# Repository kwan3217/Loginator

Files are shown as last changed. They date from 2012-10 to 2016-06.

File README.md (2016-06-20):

# Loginator
The [https://www.sparkfun.com/products/retired/8627 Sparkfun Logomatic] is a single-board computer marketed as a data logger. When I got mine, it didn't take me long to realize that this was a much more powerful computer, capable of such things as robot control. I took the original hardware design and made several derivative boards, including one which has been in space, one which has logged data on rollercoasters around the country, and one which has been to Europe and back.

This code is a complete rewrite of the firmware in C++. All original Sparkfun code has been replaced. Having said that, in the spirit of Open Source, the software is GPL 3.0 because I choose it to be, and the hardware design is CC-BY-SA because it is still derived from the original Sparkfun design.

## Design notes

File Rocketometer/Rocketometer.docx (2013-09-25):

Rocketometer Operator’s guide

Chris Jeppesen, 24 Sep 2013

1) Mechanical

The user interface includes two buttons and one power switch. The buttons include one reset button, and one button intended to switch from USB Mass Storage readout to main Rocketometer mode (boot). The reset button has been disabled by removing the solder bridge next to it. The boot button doesn’t actually do anything, so it doesn’t need to be rendered inert.

The power switch should be glued or otherwise secured in the ON position, with the switch closer to the word ON and closer to the edge of the board.

The SD card should also be glued into place, with something that can be peeled off to remove the card after flight.

Some components on the board are very close to the mounting holes. They are technically out of the keepout zone for the screw head, but too close for comfort. It would be great if rubber, paper, or some other non-conducting washers could be used to protect these components.

2) Indicator lights

The board has four colors of lights, yellow, red, green, blue.

The yellow light is on whenever the charging circuit is charging the battery. It is off when there is no external power OR when the battery is fully charged.

The RGB diode is green for the first few seconds during board startup. It then flickers through all of the colors slowly when the board is not vertical and has not been for 20 minutes. It flickers quickly when the board has been vertical within the last 20 minutes. To be precise, each time it writes a sector to the SD card, it toggles one of the colors on or off, and it cycles through the colors in turn. Since more data is generated in vertical mode, sectors are written more quickly, so the light blinks more quickly.

When the board is in slow recording mode, it flickers one light on, all off, next light on, etc, with the light on for noticeably less than 1 second. When the board is in blinklock (see Trouble below), the light is on for exactly 1 second, then off for 1 second, etc. This is noticeably slower than slow recording mode. It takes a bit of care to notice the difference, but no special tools other than the Mark I Eyeball.

3) Power

The board has a +5V input, which it uses to run all functions and charge the battery while powered. When unpowered, the board automatically and seamlessly switches to battery power. This board, with slightly different software, has been observed to run for about 2.5 hours before draining the battery. This means that the board has a power draw of significantly less than 100mA. The battery is rated at 110mAh.

The +5V input also charges the battery. The board carries the proper LiPo charging circuit and the battery has an integrated LiPo protection circuit which among other things prevents overcharge and overdischarge. Charging current is limited to 100mA, which has been observed to fully charge the battery in about 1.5 hours.

4) Trouble

If the board detects an unrecoverable error, it will enter a mode called blinklock. In this mode, the RGB diode blinks slowly, 1 second on, 1 second off. The blink is a simple binary code. The error number is communicated by blinking green for a 1 bit and red for a 0 bit, least significant bit first. When all 1 bits have been blinked, the blue light blinks indicating that the full number has been blinked out, then the process repeats, blinking the same number forever until the device is reset or power-cycled.

Let’s say the blink code is 404. In binary this is 1_1001_0100, so the code would be R R G R G R R G G B endlessly repeated. The first blink after a blue light is the first blink in this cycle.

There is no table of blink codes except for the source code. The code would have to be examined to determine the exact cause. If you encounter a blink code, notify me and disable power (and battery if possible, otherwise you have to wait for the battery to drain) to reset the board.

5) File generation

The Rocketometer writes files in the standard FAT32 filesystem, with some tweaks. In particular, the card has been formatted with the largest possible cluster size and only one file allocation table, to optimize writing speed. Any normal operating system should be able to read this card with no issue, and it has been tested with standard Microsoft Windows 7 and Linux, which did read it with no issue.

Files are named in the format RKTO%04d.SDS, where %04d indicates four decimal digits. These digits are the serial number for the file.

Each time the board starts up, it will search the card, starting with a serial number of 0 and incrementing it by 10 each time. When it does not find a file corresponding to this serial number, it stops searching and creates a new file with this number. In this case, if the card is repeatedly restarted, it will count

RKTO0000.SDS

RKTO0010.SDS

RKTO0020.SDS

etc.

Files are capped at 1GiB. When the current file size reaches this amount, the file is closed. The card is searched again starting at the next higher serial number and incrementing by 1 each time.

At high data rate, the card will hit this 1GiB file size in about 1 day. If the card ran for 10 days straight starting with a serial number of 0, it would reach serial number 10. This still isn’t a problem, when the card is reset it will skip that 10 and go on to the next multiple. No data will be overwritten.

The root directory can hold 2048 files. It is unlikely that this number will be reached, as it would involve being power-cycled that many times.

Since this is a 16GiB card, it can record for about 16 days at high rate and 160 days at low rate. There should be no problem with either number of files or data volume.

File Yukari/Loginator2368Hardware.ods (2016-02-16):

Hardware type | Serial Number
3 | 1 | Loginator2368 Hardware | Loginator2368 Hardware

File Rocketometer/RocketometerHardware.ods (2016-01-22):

Hardware type | Serial Number
2 | 2 | Rocketometer Hardware | Rocketometer Hardware

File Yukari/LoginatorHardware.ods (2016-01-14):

Hardware type | Serial Number
1 | 1 | Loginator Hardware | Loginator Hardware

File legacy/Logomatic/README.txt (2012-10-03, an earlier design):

Logomatic Firmware with SDHC and FAT32
Chris Jeppesen
http://stkwans.blogspot.com/
19 May 2012

OK, this empty file came with the package, so I am going to use it. This is the
stock Logomatic firmware with the bare minimum adjustments needed to use the
latest sd_raw and fat libraries which have SDHC and fat32 activated, 
respectively. To use, copy FW.SFE to the root directory of the Logomatic card,
then power up the card with the USB disconnected. The USB bootloader will
copy the firmware to the controller's flash memory then delete FW.SFE off of 
the card. Once done, the logger program should work exactly as before, just 
with the ability to work with SDHC cards and FAT32 file systems. The program 
still works with SD normal capacity and FAT16 file systems as well.

While this program recognizes SDHC and FAT32, by itself it does not make the 
bootloader do also. I have a USB bootloader modified similarly, but if you 
don't use that bootloader, you will need to write FW.SFE to ad SD normal 
capacity (<=2GB, not marked SDHC) card formatted as FAT16. It still might not 
work, since the bootloader tries to read the card each time it starts up to see 
if it needs to install FW.SFE, and since it can't read an SDHC card, it may 
never boot the main firmware. Best to get my USB bootloader also, just in case. 
Find it on my blog in the same place you found this code.

Sparkfun published the code with no explicit license, but since so much of it 
is GPL and LGPL, I can presume that all of it is, so my changes are GPL'd also. 
I really didn't do that much. I stand on the shoulders of giants. Anyone is 
allowed to do whatever they want with it within the limits of the GPL (3.0 or 
later). Specifically, Sparkfun is allowed to use my changes and do whatever 
they need to do to put this program onto production Logomatics, just as they 
have been doing, whether this is technically allowed by the GPL or not.

The code works for me, but there are almost certainly bugs in it. It is hoped 
that this code is useful, but there is NO WARRANTY, as specified by the GPL. If 
this code causes your house to burn down, it's your fault. If you have any bug 
fixes, you are welcome to send them to me, and if the changes work for me, I 
will include them in the hypothetical next revision.

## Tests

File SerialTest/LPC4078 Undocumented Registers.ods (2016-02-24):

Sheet: Sheet1
0 | 1048576 | 100000 |  |  | base | 1048576
1 | 1048580 | 100004
2 | 1048584 | 100008
3 | 1048588 | 10000C
4 | 1048592 | 100010
5 | 1048596 | 100014
6 | 1048600 | 100018
7 | 1048604 | 10001C
8 | 1048608 | 100020
9 | 1048612 | 100024
10 | 1048616 | 100028
11 | 1048620 | 10002C
12 | 1048624 | 100030
13 | 1048628 | 100034
14 | 1048632 | 100038
15 | 1048636 | 10003C
16 | 1048640 | 100040
17 | 1048644 | 100044
18 | 1048648 | 100048
19 | 1048652 | 10004C
20 | 1048656 | 100050
21 | 1048660 | 100054
22 | 1048664 | 100058
23 | 1048668 | 10005C
24 | 1048672 | 100060
25 | 1048676 | 100064
26 | 1048680 | 100068
27 | 1048684 | 10006C
28 | 1048688 | 100070
29 | 1048692 | 100074
30 | 1048696 | 100078
31 | 1048700 | 10007C
32 | 1048704 | 100080
33 | 1048708 | 100084
34 | 1048712 | 100088
35 | 1048716 | 10008C
36 | 1048720 | 100090
37 | 1048724 | 100094
38 | 1048728 | 100098
39 | 1048732 | 10009C
40 | 1048736 | 1000A0
41 | 1048740 | 1000A4
42 | 1048744 | 1000A8
43 | 1048748 | 1000AC
44 | 1048752 | 1000B0
45 | 1048756 | 1000B4
46 | 1048760 | 1000B8
47 | 1048764 | 1000BC
48 | 1048768 | 1000C0
49 | 1048772 | 1000C4
50 | 1048776 | 1000C8
51 | 1048780 | 1000CC
52 | 1048784 | 1000D0
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

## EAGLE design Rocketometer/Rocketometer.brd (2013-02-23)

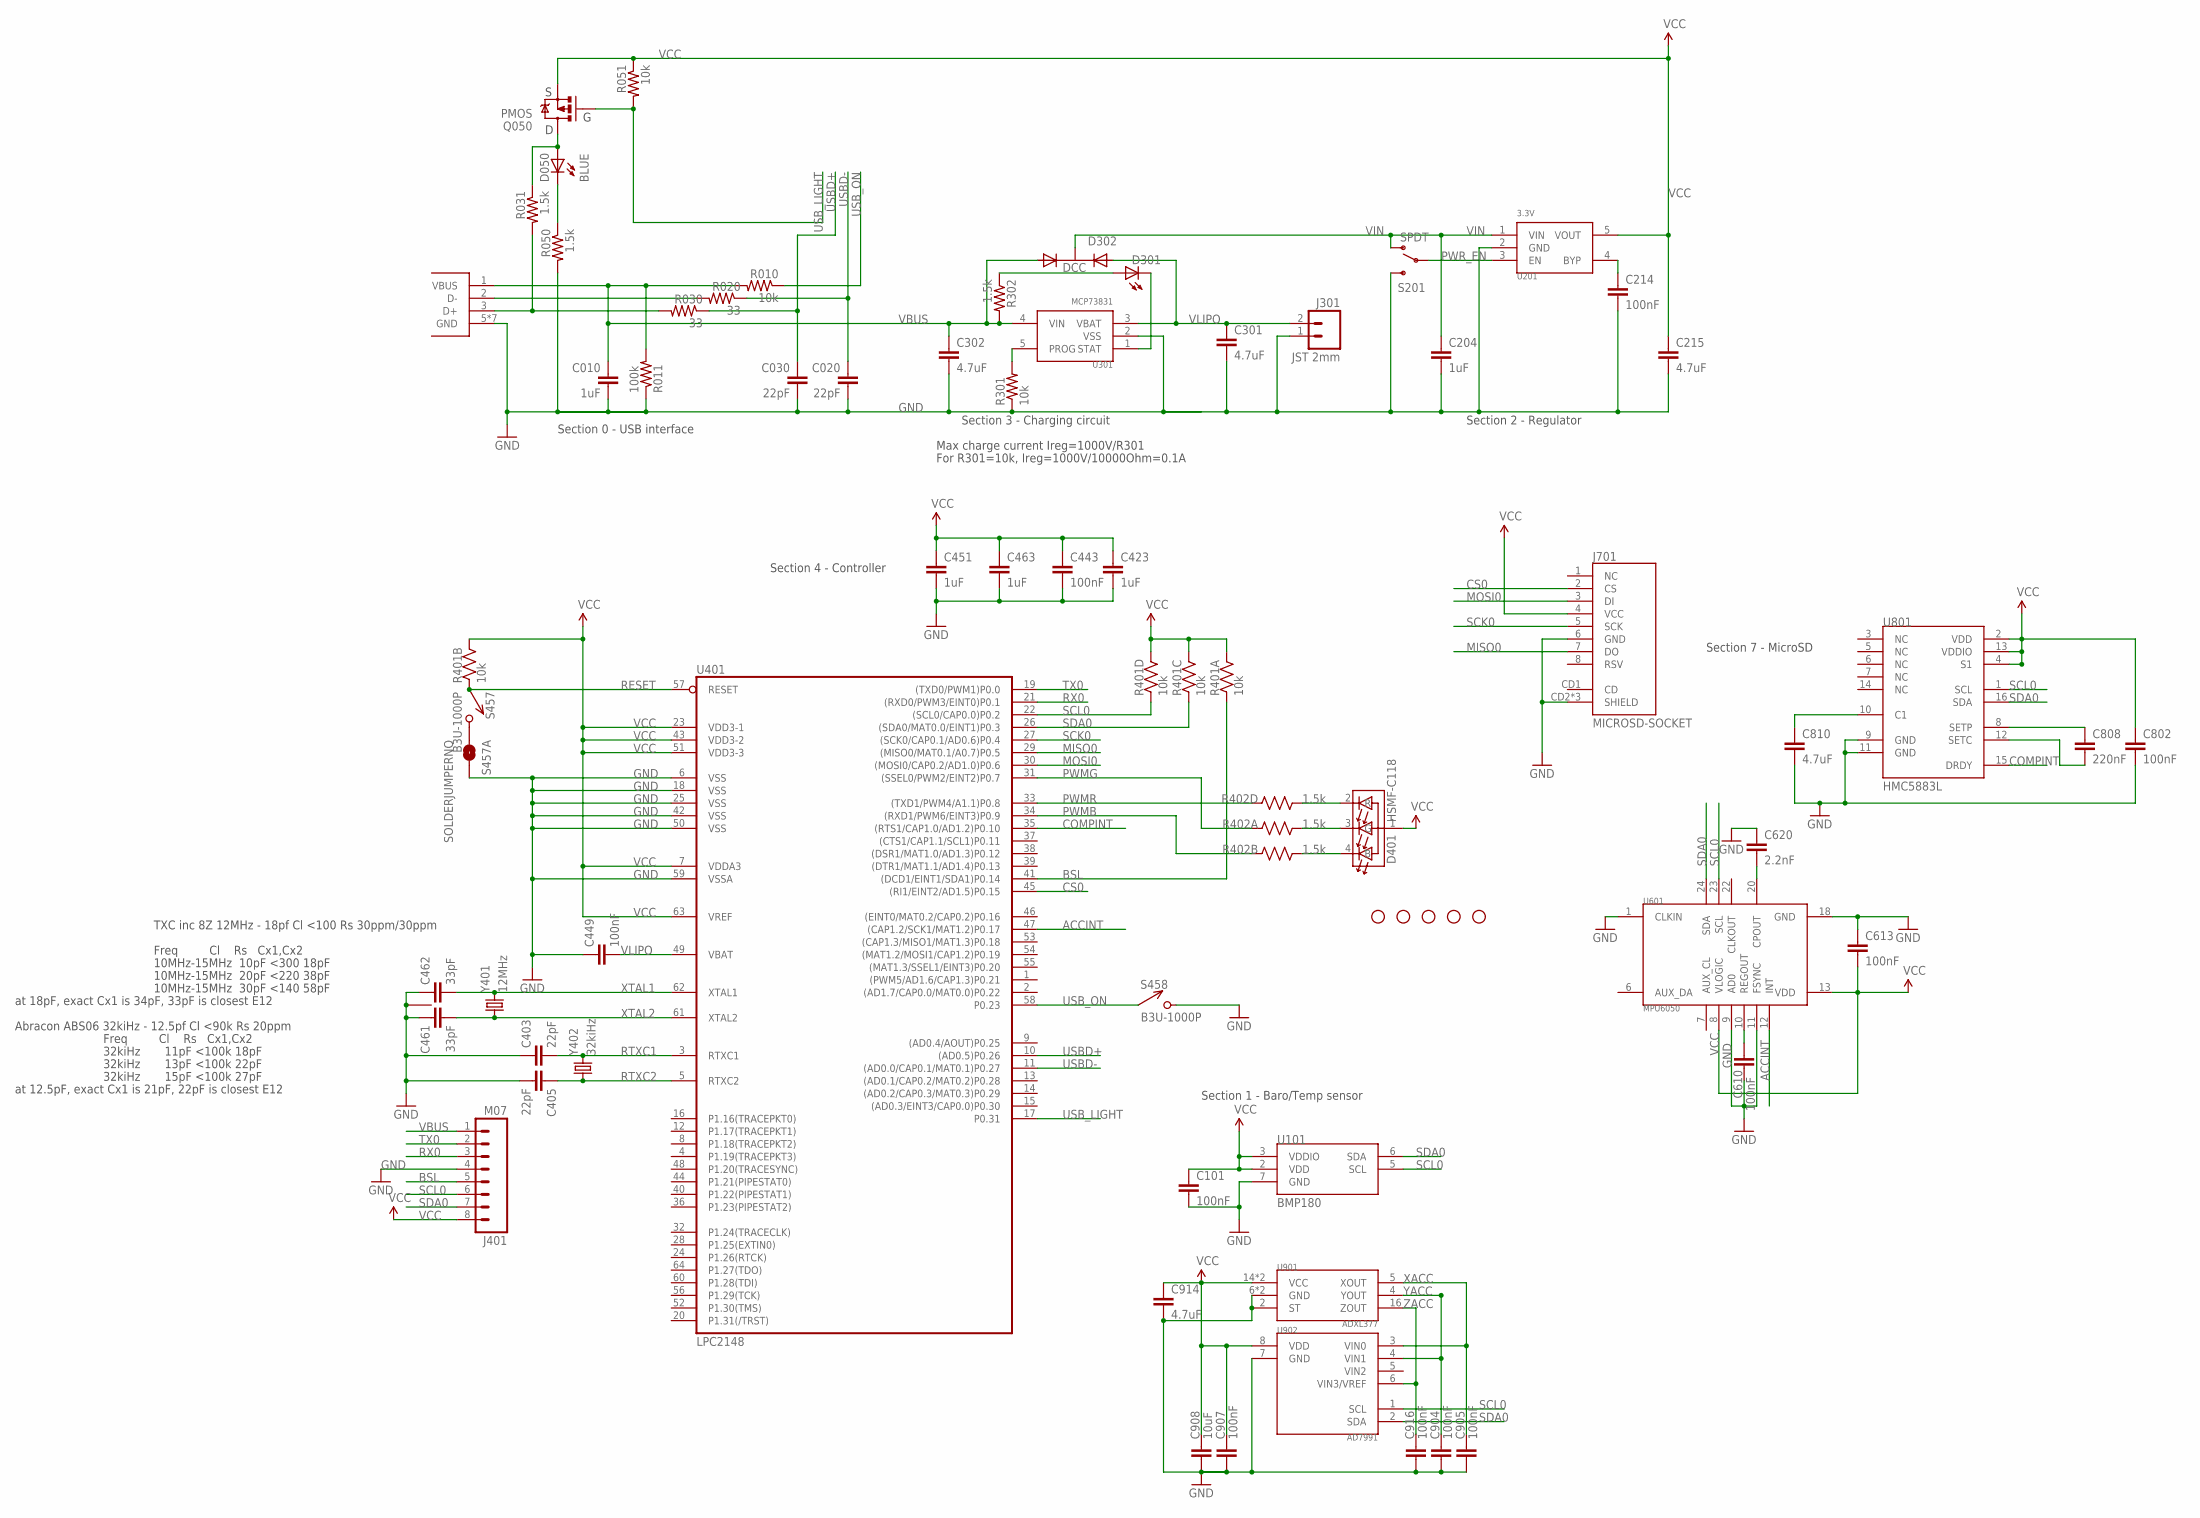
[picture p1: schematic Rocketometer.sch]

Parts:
C010, C204, C423, C451, C463: 1uF; 0402-CAP; DIGIKEY 445-4114-1-ND
C020, C030, C403, C405: 22pF; 0402-CAP; DIGIKEY 445-1239-1-ND
C101, C214, C443, C449, C610, C613, C802, C904, C905, C907, C916: 100nF; 0402-CAP; DIGIKEY 445-1265-1-ND
C215, C301, C302, C810, C914: 4.7uF; 0402-CAP; DIGIKEY 445-7395-1-ND
C461, C462: 33pF; 0402-CAP; DIGIKEY 445-1241-1-ND
C620: 2.2nF; 0402-CAP; DIGIKEY 445-1257-1-ND
C808: 220nF; 0402-CAP; DIGIKEY 445-5938-1-ND
C908: 10uF; 0603-CAP; DIGIKEY 445-7486-1-ND
D050: BLUE; LED-0603; DIGIKEY 350-2037-1-ND
D301: YELLOW; LED-0603; DIGIKEY 350-2032-1-ND
D302: DCC; SOT-23-3; DIGIKEY 568-6500-1-ND
D401: HSMF-C118; DIGIKEY 516-1778-1-ND
J001: USB_MICROB_JST; UB-MC5BR3-SD204-4S; DIGIKEY 455-2562-1-ND
J301: JST 2mm; JST-2-SMD; DIGIKEY 455-1749-1-ND
J401: M07; 1X08; DIGIKEY $NOPART
J701: MICROSD-SOCKET; MICROSD-SOCKET-PP; DIGIKEY 101-00581-59-1-ND
JP1, JP2, JP3, JP4, JP5: STAND-OFFTIGHT; STAND-OFF-TIGHT; DIGIKEY $NOPART
Q050: PMOS; SOT23-3; DIGIKEY NTR1P02T1GOSCT-ND
R010, R051, R301: 10k; 0402-RES; DIGIKEY P10.0KLCT-ND
R011: 100k; 0402-RES; DIGIKEY P100KLCT-ND
R020, R030: 33; 0402-RES; DIGIKEY P33.0LCT-ND
R031, R050, R302: 1.5k; 0402-RES; DIGIKEY P1.50KLCT-ND
R401: 10k; CRA04; DIGIKEY CRA4S810KCT-ND
R402: 1.5k; CRA04; DIGIKEY CRA4S81.5KCT-ND
S201: SPDT; AYZ0202; DIGIKEY 401-2013-1-ND
S457, S458: B3U-1000P; DIGIKEY SW1020CT-ND
S457A: SOLDERJUMPERNO; SJ_2S-NO; DIGIKEY $NOPART
U101: BMP180; DIGIKEY 828-1027-1-ND
U201: 3.3V; SOT-23-5; DIGIKEY 576-1910-1-ND
U301: MCP73831; SOT-23-5; DIGIKEY 576-1910-1-ND
U401: LPC2148; SQFP-S-10X10-64; DIGIKEY 568-1765-ND
U601: MPU6050; MPU60X0; DIGIKEY $NOPART
U801: HMC5883L; 16LPCC; DIGIKEY 342-1082-1-ND
U901: ADXL377; DIGIKEY ADXL377BCPZ-RL7CT-ND
U902: AD7991; SOT-23-8; DIGIKEY AD7991YRJZ-0500RL7CT-ND
Y401: 12MHz; CRYSTAL_SMD_2MM_2_5MM; DIGIKEY 887-1487-1-ND
Y402: 32kiHz; ABS06; DIGIKEY 535-10104-1-ND

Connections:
ACCINT: U401.47 ((CAP1.2/SCK1/MAT1.2)P0.17), U601.12 (INT)
BSL: J401.5, R401.1, U401.41 ((DCD1/EINT1/SDA1)P0.14)
COMPINT: U401.35 ((RTS1/CAP1.0/AD1.2)P0.10), U801.15 (DRDY)
CONN_D+: J001.3 (D+), R030.2, R031.2
CONN_D-: J001.2 (D-), R020.2
CS0: J701.2 (CS), U401.45 ((RI1/EINT2/AD1.5)P0.15)
GND: C010.2, C020.2, C030.2, C101.2, C204.2, C214.2, C215.2, C301.2, C302.2, C403.1, C405.2, C423.2, C443.2, C449.1, C451.2, C461.1, C462.1, C463.2, C610.2, C613.1, C620.1, C802.2, C810.2, C904.2, C905.2, C907.2, C908.2, C914.2, C916.2, J001.5 (GND), J001.P$6 (GND), J001.P$7 (GND), J001.P$8 (GND), J001.P$9 (GND), J001.P$10 (GND), J001.P$11 (GND), J301.1, J401.4, J701.6 (GND), J701.CD2 (SHIELD), J701.GND1 (SHIELD), J701.GND3 (SHIELD), R011.1, R050.2, R301.1, S201.3 (S), S457A.2, S458.P$2 (2), U101.7 (GND), U201.2 (GND), U301.2 (VSS), U401.6 (VSS), U401.18 (VSS), U401.25 (VSS), U401.42 (VSS), U401.50 (VSS), U401.59 (VSSA), U601.1 (CLKIN), U601.9 (AD0), U601.11 (FSYNC), U601.18 (GND), U801.9 (GND), U801.11 (GND), U901.2 (ST), U901.6 (GND), U901.7 (GND), U902.7 (GND), Y401.2 (1), Y401.4 (1)
MISO0: J701.7 (DO), U401.29 ((MISO0/MAT0.1/A0.7)P0.5)
MOSI0: J701.3 (DI), U401.30 ((MOSI0/CAP0.2/AD1.0)P0.6)
unnamed: C620.2, U601.20 (CPOUT)
unnamed: R301.2, U301.5 (PROG)
unnamed: D301.C, U301.1 (STAT)
unnamed: D301.A, R302.1
unnamed: D050.A, Q050.3 (D), R031.1
unnamed: D050.C, R050.1
unnamed: S457.P$2 (2), S457A.1
unnamed: C610.1, U601.10 (REGOUT)
unnamed: C808.1, U801.8 (SETP)
unnamed: C808.2, U801.12 (SETC)
unnamed: C810.1, U801.10 (C1)
unnamed: C214.1, U201.4 (BYP)
PWMB: R402.7 (2), U401.34 ((RXD1/PWM6/EINT3)P0.9)
PWMG: R402.8 (2), U401.31 ((SSEL0/PWM2/EINT2)P0.7)
PWMR: R402.5 (2), U401.33 ((TXD1/PWM4/A1.1)P0.8)
PWR_EN: S201.2, U201.3 (EN)
QWMB: D401.4 (B), R402.2 (1)
QWMG: D401.3 (G), R402.1
QWMR: D401.2 (R), R402.4 (1)
RESET: R401.2 (1), S457.P$1 (1), U401.57 (RESET)
RTXC1: C403.2, U401.3 (RTXC1), Y402.2
RTXC2: C405.1, U401.5 (RTXC2), Y402.1
RX0: J401.3, U401.21 ((RXD0/PWM3/EINT0)P0.1)
SCK0: J701.5 (SCK), U401.27 ((SCK0/CAP0.1/AD0.6)P0.4)
SCL0: J401.6, R401.4 (1), U101.5 (SCL), U401.22 ((SCL0/CAP0.0)P0.2), U601.23 (SCL), U801.1 (SCL), U902.1 (SCL)
SDA0: J401.7, R401.3 (1), U101.6 (SDA), U401.26 ((SDA0/MAT0.0/EINT1)P0.3), U601.24 (SDA), U801.16 (SDA), U902.2 (SDA)
TX0: J401.2, U401.19 ((TXD0/PWM1)P0.0)
USBD+: C030.1, R030.1, U401.10 ((AD0.5)P0.26)
USBD-: C020.1, R020.1, U401.11 ((AD0.0/CAP0.1/MAT0.1)P0.27)
USB_LIGHT: Q050.1 (G), R051.2, U401.17 (P0.31)
USB_ON: R010.1, S458.P$1 (1), U401.58 (P0.23)
VBUS: C010.1, C302.1, D302.1 (A1), J001.1 (VBUS), J401.1, R010.2, R011.2, R302.2, U301.4 (VIN)
VCC: C101.1, C215.1, C423.1, C443.1, C451.1, C463.1, C613.2, C802.1, C907.1, C908.1, C914.1, D401.1 (A), J401.8, J701.4 (VCC), Q050.2 (S), R051.1, R401.5 (2), R401.6 (2), R401.7 (2), R401.8 (2), U101.2 (VDD), U101.3 (VDDIO), U201.5 (VOUT), U401.7 (VDDA3), U401.23 (VDD3-1), U401.43 (VDD3-2), U401.51 (VDD3-3), U401.63 (VREF), U601.8 (VLOGIC), U601.13 (VDD), U801.2 (VDD), U801.4 (S1), U801.13 (VDDIO), U901.14 (VCC), U901.15 (VCC), U902.8 (VDD)
VIN: C204.1, D302.3 (K), S201.1 (O), U201.1 (VIN)
VLIPO: C301.1, C449.2, D302.2 (A2), J301.2, U301.3 (VBAT), U401.49 (VBAT)
XACC: C905.1, U901.5 (XOUT), U902.3 (VIN0)
XTAL1: C462.2, U401.62 (XTAL1), Y401.3 (2)
XTAL2: C461.2, U401.61 (XTAL2), Y401.1
YACC: C904.1, U901.4 (YOUT), U902.4 (VIN1)
ZACC: C916.1, U901.16 (ZOUT), U902.6 (VIN3/VREF)

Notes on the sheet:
Section 2 - Regulator
Section 3 - Charging circuit
Section 0 - USB interface
Section 4 - Controller
Section 7 - MicroSD
Section 1 - Baro/Temp sensor
Max charge current Ireg=1000V/R301
For R301=10k, Ireg=1000V/10000Ohm=0.1A
Freq Cl Rs Cx1,Cx2
10MHz-15MHz 10pF <300 18pF
10MHz-15MHz 20pF <220 38pF
10MHz-15MHz 30pF <140 58pF
TXC inc 8Z 12MHz - 18pf Cl <100 Rs 30ppm/30ppm
at 18pF, exact Cx1 is 34pF, 33pF is closest E12
32kiHz 11pF <100k 18pF
32kiHz 13pF <100k 22pF
32kiHz 15pF <100k 27pF
Abracon ABS06 32kiHz - 12.5pf Cl <90k Rs 20ppm
at 12.5pF, exact Cx1 is 21pF, 22pF is closest E12

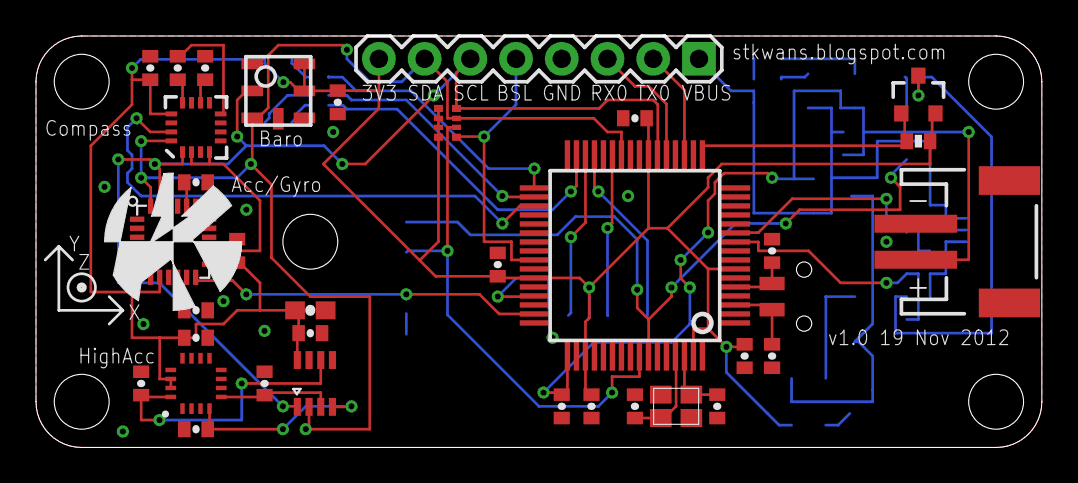
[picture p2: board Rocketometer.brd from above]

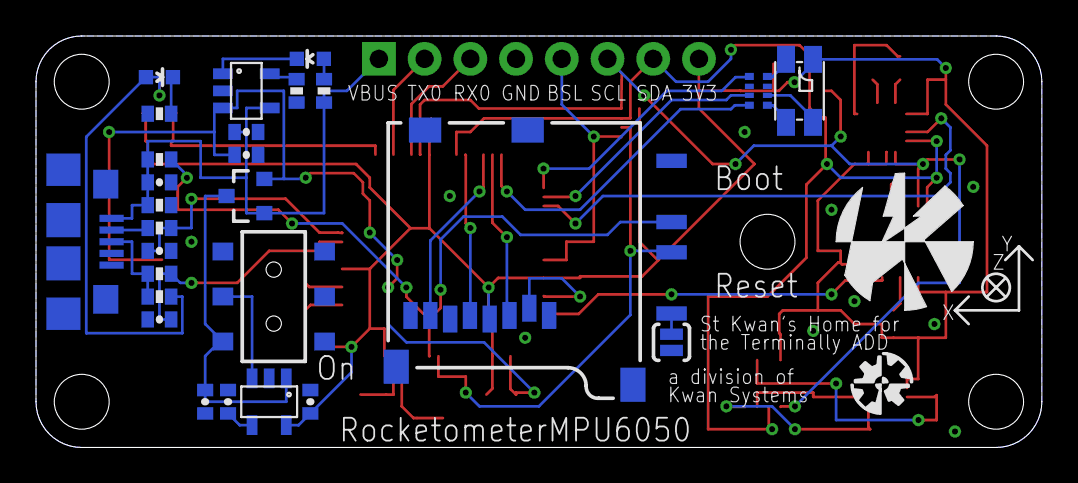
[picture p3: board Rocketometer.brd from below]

Board: 2 copper layers, 55.9 x 22.9 mm, 73 parts (31 on the bottom side), 49 nets.

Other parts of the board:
U$1, U$5: KWAN_ACC
U$4: AXES
U$6: OSHW_ACC

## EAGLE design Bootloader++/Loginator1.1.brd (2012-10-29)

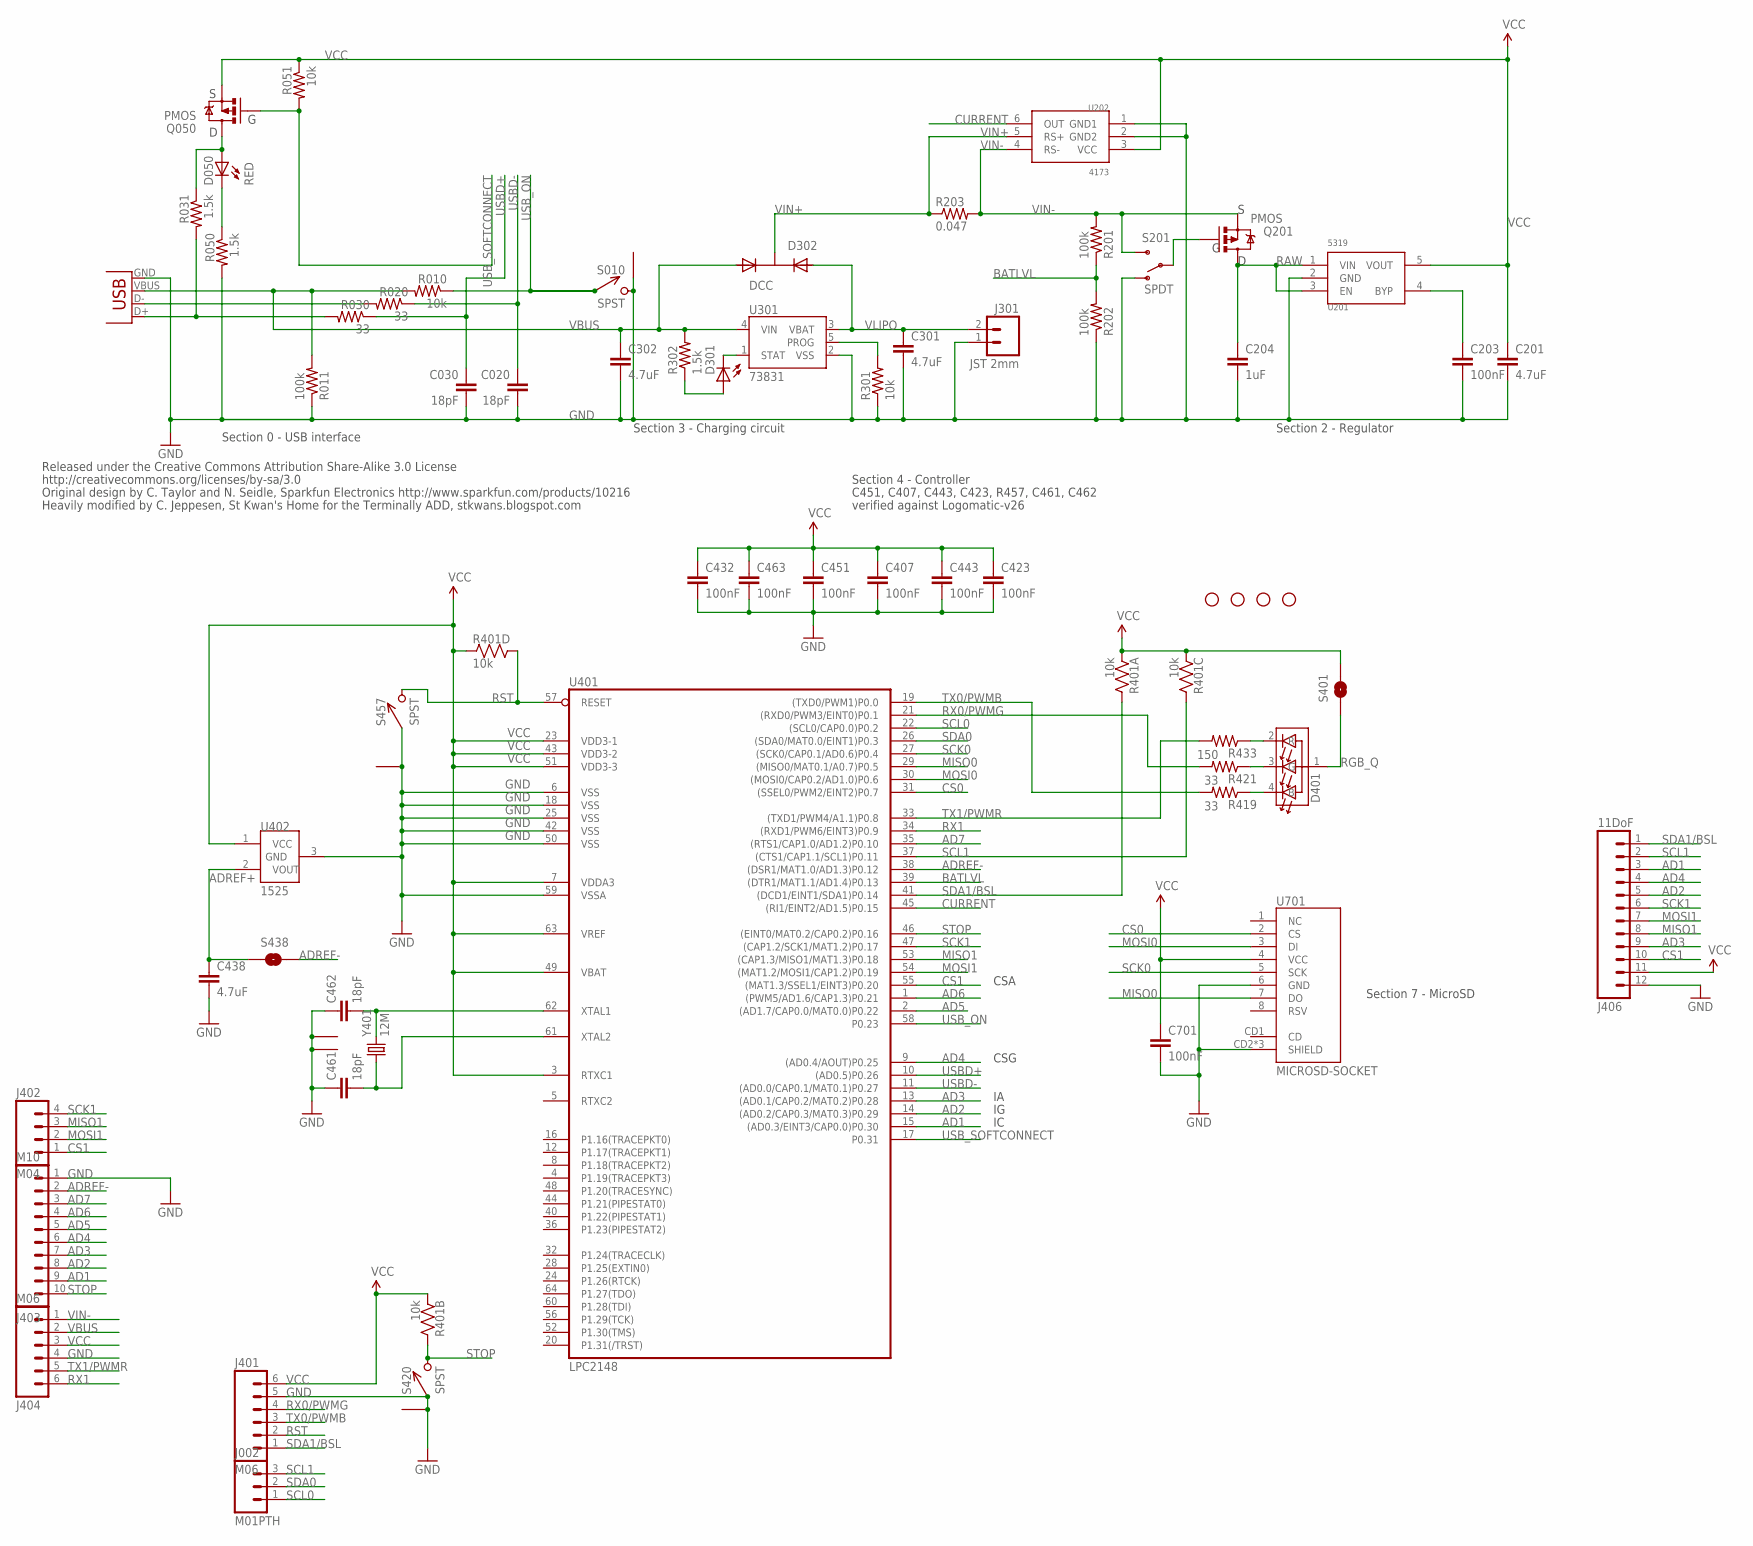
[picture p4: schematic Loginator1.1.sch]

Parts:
C020, C030, C461, C462: 18pF; 0402-CAP
C201, C301, C302, C438: 4.7uF; 0402-CAP
C203, C407, C423, C432, C443, C451, C463, C701: 100nF; 0402-CAP
C204: 1uF; 0402-CAP
D050, D301: RED; LED-0603
D302: DCC; SOT-23-3
D401: HSMF-C118
J001: USBSMD; USB-MINIB
J002: M01PTH; 1X03
J301: JST 2mm; JST-2-SMD
J401, J404: M06; 1X06
J402: M04; 1X04
J403: M10; 1X10
J406: 11DoF; 1X12
JP1, JP2, JP3, JP4: STAND-OFF
Q050, Q201: PMOS; SOT23-3
R010, R051, R301: 10k; 0402-RES
R011, R201, R202: 100k; 0402-RES
R020, R030, R419, R421: 33; 0402-RES
R031, R050, R302: 1.5k; 0402-RES
R203: 0.047; 0402-RES
R401: 10k; CRA04
R433: 150; 0402-RES
S010, S420, S457: SPST; B3U-1100P
S201: SPDT; AYZ0202
S401, S438: SOLDERJUMPERNO; SJ_2S-NO
U201: 5319; SOT-23-5
U202: 4173; SOT-23-6
U301: 73831; SOT23-5
U401: LPC2148; SQFP-S-10X10-64
U402: 1525; SOT-23-3
U701: MICROSD-SOCKET; MICROSD-SOCKET-PP
Y401: 12M; CRYSTAL_SMD

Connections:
AD1: J403.9, J406.3, U401.15 ((AD0.3/EINT3/CAP0.0)P0.30)
AD2: J403.8, J406.5, U401.14 ((AD0.2/CAP0.3/MAT0.3)P0.29)
AD3: J403.7, J406.9, U401.13 ((AD0.1/CAP0.2/MAT0.2)P0.28)
AD4: J403.6, J406.4, U401.9 ((AD0.4/AOUT)P0.25)
AD5: J403.5, U401.2 ((AD1.7/CAP0.0/MAT0.0)P0.22)
AD6: J403.4, U401.1 ((PWM5/AD1.6/CAP1.3)P0.21)
AD7: J403.3, U401.35 ((RTS1/CAP1.0/AD1.2)P0.10)
ADREF+: C438.1, S438.1, U402.2 (VOUT)
ADREF-: J403.2, S438.2, U401.38 ((DSR1/MAT1.0/AD1.3)P0.12)
BATLVL: R201.1, R202.2, U401.39 ((DTR1/MAT1.1/AD1.4)P0.13)
CONN_D+: J001.D+, R030.2, R031.2
CONN_D-: J001.D-, R020.2
CS0: U401.31 ((SSEL0/PWM2/EINT2)P0.7), U701.2 (CS)
CS1: J402.1, J406.10, U401.55 ((MAT1.3/SSEL1/EINT3)P0.20)
CURRENT: U202.6 (OUT), U401.45 ((RI1/EINT2/AD1.5)P0.15)
DB: D401.4 (B), R419.1
DG: D401.3 (G), R421.1
DR: D401.2 (R), R433.1
GND: C020.2, C030.2, C201.2, C203.2, C204.2, C301.2, C302.2, C407.2, C423.2, C432.2, C438.2, C443.2, C451.2, C461.1, C462.1, C463.2, C701.2, J001.GND, J301.1, J401.5, J403.1, J404.4, J406.12, R011.1, R050.2, R202.1, R301.1, S010.P$2 (2), S010.P$3 (1), S201.1 (O), S420.P$1 (1), S420.P$3 (1), S457.P$1 (1), S457.P$3 (1), U201.2 (GND), U202.1 (GND1), U202.2 (GND2), U301.2 (VSS), U401.6 (VSS), U401.18 (VSS), U401.25 (VSS), U401.42 (VSS), U401.50 (VSS), U401.59 (VSSA), U402.3 (GND), U701.6 (GND), U701.CD2 (SHIELD), U701.GND1 (SHIELD), U701.GND3 (SHIELD), Y401.2 (1), Y401.4 (1)
MISO0: U401.29 ((MISO0/MAT0.1/A0.7)P0.5), U701.7 (DO)
MISO1: J402.3, J406.8, U401.53 ((CAP1.3/MISO1/MAT1.3)P0.18)
MOSI0: U401.30 ((MOSI0/CAP0.2/AD1.0)P0.6), U701.3 (DI)
MOSI1: J402.2, J406.7, U401.54 ((MAT1.2/MOSI1/CAP1.2)P0.19)
unnamed: D301.A, R302.1
unnamed: R301.2, U301.5 (PROG)
unnamed: D301.C, U301.1 (STAT)
unnamed: D050.A, Q050.3 (D), R031.1
unnamed: D050.C, R050.1
unnamed: Q201.1 (G), S201.2
unnamed: C203.1, U201.4 (BYP)
RAW: C204.1, Q201.3 (D), U201.1 (VIN), U201.3 (EN)
RGB_Q: D401.1 (A), S401.1
RST: J401.2, R401.5 (2), S457.P$2 (2), U401.57 (RESET)
RX0/PWMG: J401.4, R421.2, U401.21 ((RXD0/PWM3/EINT0)P0.1)
RX1: J404.6, U401.34 ((RXD1/PWM6/EINT3)P0.9)
SCK0: U401.27 ((SCK0/CAP0.1/AD0.6)P0.4), U701.5 (SCK)
SCK1: J402.4, J406.6, U401.47 ((CAP1.2/SCK1/MAT1.2)P0.17)
SCL0: J002.1, U401.22 ((SCL0/CAP0.0)P0.2)
SCL1: J002.3, J406.2, R401.6 (2), U401.37 ((CTS1/CAP1.1/SCL1)P0.11)
SDA0: J002.2, U401.26 ((SDA0/MAT0.0/EINT1)P0.3)
SDA1/BSL: J401.1, J406.1, R401.8 (2), U401.41 ((DCD1/EINT1/SDA1)P0.14)
STOP: J403.10, R401.7 (2), S420.P$2 (2), U401.46 ((EINT0/MAT0.2/CAP0.2)P0.16)
TX0/PWMB: J401.3, R419.2, U401.19 ((TXD0/PWM1)P0.0)
TX1/PWMR: J404.5, R433.2, U401.33 ((TXD1/PWM4/A1.1)P0.8)
USBD+: C030.1, R030.1, U401.10 ((AD0.5)P0.26)
USBD-: C020.1, R020.1, U401.11 ((AD0.0/CAP0.1/MAT0.1)P0.27)
USB_ON: R010.1, S010.P$1 (1), U401.58 (P0.23)
USB_SOFTCONNECT: Q050.1 (G), R051.2, U401.17 (P0.31)
VBUS: C302.1, D302.1 (A1), J001.VBUS, J404.2, R010.2, R011.2, R302.2, U301.4 (VIN)
VCC: C201.1, C407.1, C423.1, C432.1, C443.1, C451.1, C463.1, C701.1, J401.6, J404.3, J406.11, Q050.2 (S), R051.1, R401.1, R401.2 (1), R401.3 (1), R401.4 (1), S401.2, U201.5 (VOUT), U202.3 (VCC), U401.3 (RTXC1), U401.7 (VDDA3), U401.23 (VDD3-1), U401.43 (VDD3-2), U401.49 (VBAT), U401.51 (VDD3-3), U401.63 (VREF), U402.1 (VCC), U701.4 (VCC)
VIN+: D302.3 (K), R203.1, U202.5 (RS+)
VIN-: J404.1, Q201.2 (S), R201.2, R203.2, S201.3 (S), U202.4 (RS-)
VLIPO: C301.1, D302.2 (A2), J301.2, U301.3 (VBAT)
XTAL1: C462.2, U401.62 (XTAL1), Y401.3 (2)
XTAL2: C461.2, U401.61 (XTAL2), Y401.1

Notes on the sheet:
Section 4 - Controller
Section 7 - MicroSD
C451, C407, C443, C423, R457, C461, C462
verified against Logomatic-v26
Section 2 - Regulator
Section 3 - Charging circuit
Section 0 - USB interface
Released under the Creative Commons Attribution Share-Alike 3.0 License
http://creativecommons.org/licenses/by-sa/3.0
Original design by C. Taylor and N. Seidle, Sparkfun Electronics http://www.sparkfun.com/products/10216
Heavily modified by C. Jeppesen, St Kwan's Home for the Terminally ADD, stkwans.blogspot.com
CSG
CSA

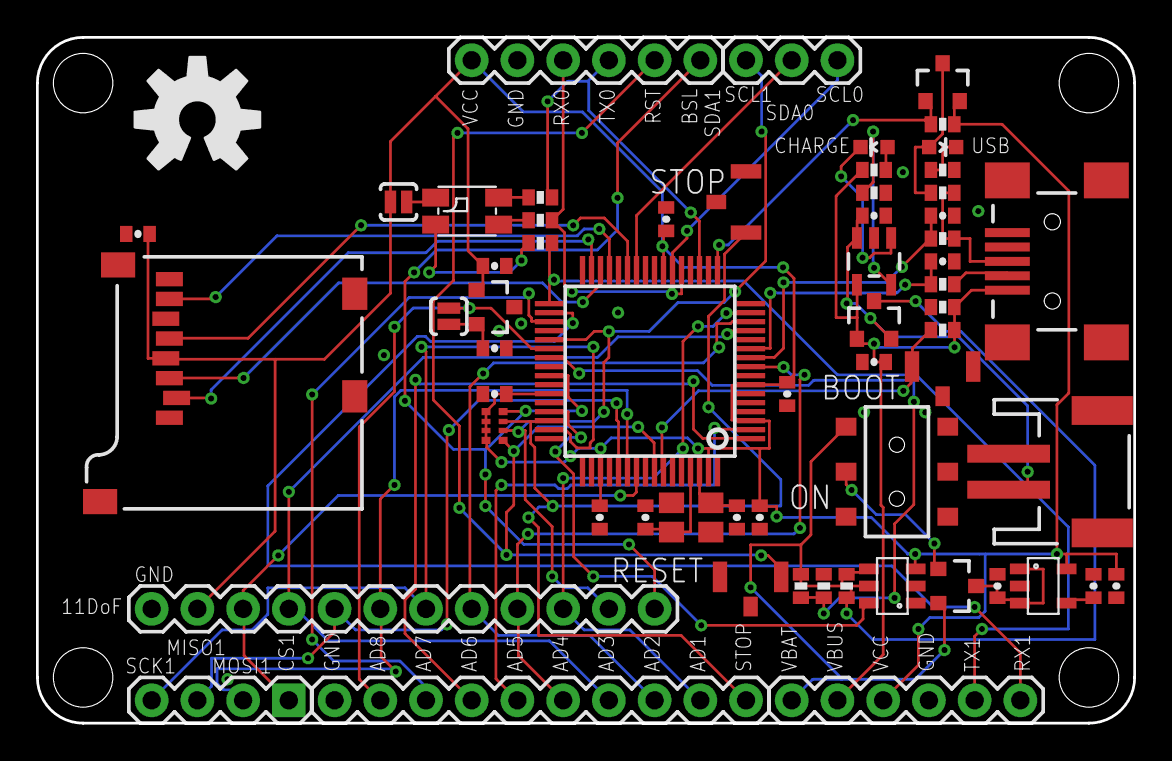
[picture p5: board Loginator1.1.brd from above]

Board: 2 copper layers, 61.0 x 38.1 mm, 66 parts (1 on the bottom side), 55 nets.

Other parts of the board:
U$1: KWAN_CIRCLE
U$2: OSHW-LOGO-L

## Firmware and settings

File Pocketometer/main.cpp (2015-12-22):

#include <string.h>
#include "Time.h"
#include "LPCduino.h"
#include "StateTwoWire.h"
#include "Serial.h"
#include "HardSPI.h"
#include "mpu60x0.h"
#include "bmp180.h"
#include "ak8975.h"
#include "sdhc.h"
#include "Partition.h"
#include "cluster.h"
#include "direntry.h"
#include "file.h"
#include "FileCircular.h"
#include "dump.h"
#include "nmea.h"
#include "readconfig.h"

const char syncMark[]="KwanSync";
static const char version_string[]="Pocketometer v0.0 " __DATE__ " " __TIME__;

StateTwoWire Wire0(0),Wire1(1);
BMP180 bmp180(&Wire1);
SDHC sd;
MPU6050 mpu6050(Wire1,0);
AK8975 ak8975(&Wire1);
Partition p(sd);
Cluster fs(p);
File f(fs);
FileCircular sdStore(f);
char serialBuf[1024];
Circular serialStore(1024,serialBuf);
CCSDS ccsds;
NMEA gps;

int gsens=3;
int asens=3;
int mpuBw=3;
int mpuSample=5;
int mpuReadMs=10;

const unsigned int maxLogSize=1024U*1024U*1024U;

const char* const ReadConfig::tagNames[]={"GSENS","ASENS","MPUBW","MPUSAMPLE","MPUREADMS","\0"};
const int   ReadConfig::tagTypes[]={ReadConfig::typeInt,ReadConfig::typeInt,ReadConfig::typeInt,ReadConfig::typeInt};
void *const ReadConfig::tagDatas[]={&gsens,&asens,&mpuBw,&mpuSample,&mpuReadMs};
int *const  ReadConfig::tagSizes[]={nullptr,nullptr,nullptr,nullptr,nullptr};
ReadConfig readconfig(fs,ccsds);

uint16_t log_i=0;

uint16_t pktseq[16];

static inline bool isRocketometer() {
  return HW_TYPE_ROCKETOMETER==HW_TYPE();
}

void openLog(uint16_t inc=1) {
  Serial.println(inc,DEC);
  Serial.println(log_i,DEC);
  if(inc==0) blinklock(108);
  static char fn[13];
  if(fn[0]!='s') strcpy(fn,"pocket00.sds");
  Serial.println(fn);
  while(log_i<99 && f.find(fn)) {
    log_i+=inc;
    fn[6]='0'+(log_i%100)/10;
    fn[7]='0'+(log_i%10);
    Serial.println(fn);
  }
  Serial.print("f.openw(\"");Serial.print(fn);Serial.print("\"): ");
  bool worked=f.openw(fn);
  Serial.print(worked?"Worked":"didn't work");Serial.print(". Status code ");Serial.println(f.errnum);
  if(!worked) blinklock(f.errnum);
}

static void closeLog() {
  f.close(); //Sync the directory entry - after this, we may reuse this file
               //object on a new file.
}

static void initSD() {
  bool worked;
  Serial.print("sd");    Serial.print(".begin ");
  worked=sd.begin();
  Serial.print(worked?"Worked":"didn't work");Serial.print(". Status code ");Serial.println(sd.errnum);
  if(!worked) blinklock(sd.errnum);

//  sd.get_info(sdinfo);
//  sdinfo.print(Serial);
  Serial.print("p");     Serial.print(".begin ");
  worked=p.begin(1);
  Serial.print(worked?"Worked":"didn't work");Serial.print(". Status code ");Serial.println(p.errnum);
//  p.print(Serial);
  if(!worked) blinklock(p.errnum);

  Serial.print("fs");    Serial.print(".begin ");
  worked=fs.begin();  
  Serial.print(worked?"Worked":"didn't work");Serial.print(". Status code ");Serial.println(fs.errnum);
//  sector.begin();
//  fs.print(Serial);//,sector);
  if(!worked) blinklock(fs.errnum);

  openLog();
  sdStore.fill(syncMark);
  sdStore.mark();

}

static void writeVersion(int apid) {
  ccsds.start(sdStore,apid,pktseq);
  ccsds.fill32(HW_TYPE());
  ccsds.fill32(HW_SERIAL());
  ccsds.fill(MAMCR());
  ccsds.fill(MAMTIM());
  ccsds.fill16(PLLSTAT(0));
  ccsds.fill(VPBDIV());
  ccsds.fill32(FOSC);                   //Crystal frequency, Hz
  ccsds.fill32(CCLK);                   //Core Clock rate, Hz
  ccsds.fill32(PCLK);                   //Peripheral Clock rate, Hz
  ccsds.fill32(PREINT());
  ccsds.fill32(PREFRAC());
  ccsds.fill(CCR());
  ccsds.fill(version_string);
  ccsds.finish(apid);
  sdStore.drain();
}

/** Dump a section of ROM to packet file
 @param start pointer to first byte to dump
 @param stop  pointer to one byte after last byte to dump
 @param apid  APID to use for the packets of this dump
 @param name  Name to print to serial port when done with dump
 */
void dumpRom(char* start, char* end, int apid, char* name) {
  const int dumpPktSize=256-6-3*sizeof(uint32_t); //Write two of these packets per sector

  int len=end-start;
  char* base=start;
  Serial.print("Dumping ");Serial.print(name);Serial.print("...");
  while(len>0) {
    ccsds.start(sdStore,apid,pktseq);
    ccsds.fill32(uint32_t(start));
    ccsds.fill32(uint32_t(end));
    ccsds.fill32(uint32_t(base));
    ccsds.fill(base,len>dumpPktSize?dumpPktSize:len);
    ccsds.finish(apid);
    sdStore.drain();
    base+=dumpPktSize;
    len-=dumpPktSize;
  }
  Serial.println("done.");
}

static void initMpu(int apid) {
  mpu6050.begin(gsens,asens,mpuBw,mpuSample);
  Serial.print("MPU6050");Serial.print(" identifier (should be '"); Serial.print("68");Serial.print("'): ");
  Serial.println(mpu6050.whoami(),HEX);
  ccsds.start(sdStore,apid,pktseq);
  mpu6050.fillConfig(ccsds);
  ccsds.finish(apid);
  sdStore.drain();

  //Priming read, not written anywhere but clears INT
  int16_t ax,ay,az,gx,gy,gz,mt;
  mpu6050.read(ax,ay,az,mt,gx,gy,gz);
  
  //On Pocketometer, set up CAP0.0 on pin P0.22 to capture (read) MPU INT
  set_pin(22,2,0);
  TCR(0,0)=0;
  TCCR(0)=(0x01 << (0*3)); //channel 3, 3 control bits per channel, capture on rising, not falling, no interrupt
}

static void initMag(int apid) {
  Serial.print("AK8975");
  ak8975.begin(&Wire1);
  Serial.println(" started");
  Serial.print("AK8975");Serial.print(" identifier (should be '");Serial.print("0x48");Serial.print("'): ");
  Serial.println(ak8975.whoami(),HEX,2);
  ccsds.start(sdStore,apid,pktseq);
  ak8975.fillConfig(ccsds);
  ccsds.finish(apid);
  sdStore.drain();
}

static void initBmp(int apid) {
  Serial.print("BMP180");Serial.print(".begin ");
  bool worked=bmp180.begin(&Wire1,2);
  Serial.print(worked?"Worked":"didn't work");Serial.print(". Status code ");Serial.println(0);
  Serial.print("BMP180");Serial.print(" identifier (should be '"); Serial.print("55");Serial.print("'): ");
  Serial.println(bmp180.whoami(),HEX);

  bmp180.ouf=0;
  ccsds.start(sdStore,apid,pktseq);

  bmp180.fillCalibration(ccsds);
  ccsds.finish(apid);
  sdStore.drain();
}

void setup() {
  Serial.begin(4800);
  Serial.println(version_string);
  Serial.print("Hardware type: ");
  Serial.println(HW_TYPE());
  if(isRocketometer()) {
    Serial.print("Can't control a Rocketometer yet");
    blinklock(0x1234);
  }
  sd.p0=7;
  Serial.print("Using Logomatic hardware, sd.p0=");
  Serial.println(sd.p0);
  initSD();

  Serial.print("Wire1 ");
  Wire1.begin();
  Serial.println(" started");

  //Write processor config and firmware version
  writeVersion(0x01);
  sdStore.drain();

  dumpRom(source_start, source_end, 0x02, "source");
  dumpRom( image_start,  image_end, 0x03, "image" );

  //Read system config
  bool worked;
  ccsds.start(sdStore,0x04,pktseq);
  Serial.print("readconfig");Serial.print(".begin ");
  worked=readconfig.begin();
  Serial.print(worked?"Worked":"didn't work");Serial.print(". Status code ");Serial.println(readconfig.errnum);
  if(!worked) blinklock(readconfig.errnum);
  ccsds.finish(0x04);
  sdStore.drain();
  
  initMpu(0x05); //MPU6050 has to be started first to set I2 bus to passthrough mode
  initMag(0x06);
  initBmp(0x07);

  ccsds.start(sdStore,0x08,pktseq);
  SDHC_info sdinfo;
  sd.get_info(sdinfo);
  sdinfo.print(Serial);
  sdinfo.fill(ccsds);
  ccsds.finish(0x08);
  sdStore.drain();
  Serial.println("Done with setup");
  Serial.flush();
  
}

//return true if sensor has updated the heading
bool collectMpuData(int apid) {
  static uint32_t gTC; ///< Last TC that we collected a measurement
         uint32_t gTCR; ///< Current TC capture value for this sensor
  gTCR=TCR(0,0);
  bool triggerOnInt=(gTC!=gTC);
  bool triggerOnTimeout=(mpuReadMs<msPassed(gTC));
  if(triggerOnInt | triggerOnTimeout) {
    gTC=triggerOnInt?gTCR:TTC(0);
    //Write an accelerometer fast packet
    int16_t ax,ay,az,gx,gy,gz,mt;
    mpu6050.read(ax,ay,az,gx,gy,gz,mt);
    ccsds.start(sdStore,apid,pktseq,gTC);
    ccsds.fill16(ax);ccsds.fill16(ay); ccsds.fill16(az); ccsds.fill16(gx); ccsds.fill16(gy); ccsds.fill16(gz); ccsds.fill16(mt); ccsds.fill(triggerOnInt?1:0); ccsds.fill(triggerOnTimeout?1:0);
    ccsds.finish(apid);
    return true;
  }
  return false;
}

void collectMagData(int apid) {
  if(ak8975.noblockMeasurement()) {
    uint32_t bTC=TTC(0);
    int16_t bx,by,bz;
    uint8_t st1,st2;
    ccsds.start(sdStore,apid,pktseq,bTC);
    ak8975.read(bx,by,bz,st1,st2);
    //Swap up magnetic axes so that they match MPU axes
    //MPU   Mag
    //+x   +y
    //+y   +x
    //+z   -z
    ccsds.fill(st1); ccsds.fill16(by);  ccsds.fill16(bx); ccsds.fill16(-bz); ccsds.fill(st2);  
    ccsds.finish(apid);
  }
}

void collectBmpData(int apid) {
  if(bmp180.noblockMeasurement()) {
    uint32_t bmpTC=TTC(0);
    uint16_t temperatureRaw=bmp180.getTemperatureRaw();
    uint32_t pressureRaw=bmp180.getPressureRaw();
    int16_t temperature=bmp180.getTemperature();
    uint32_t pressure=bmp180.getPressure();
    ccsds.start(sdStore,apid,pktseq,bmpTC);
    ccsds.fill16(temperatureRaw);
    ccsds.fill32(pressureRaw);
    ccsds.fillfp(fp(temperature)/10.0);
    ccsds.fill32(pressure);
    ccsds.finish(apid);
  }
}

bool collectGPS(int ppsApid, int nmeaApid, int ggaApid, int rmcApid) {
  bool hasGuide=false;
  while(Serial.available()>0) {
    char in=Serial.read();
    if(in=='$') {
      serialStore.mark();
      ccsds.start(sdStore,nmeaApid,pktseq,TTC(0));
      serialStore.drainPartial(sdStore);
      ccsds.finish(nmeaApid);
      Serial.write('p');
    }
    serialStore.fill(in);
//    Serial.write(in);
    gps.process(in);
  }
  if(gps.writeGGA) {
    ccsds.start(sdStore,ggaApid,pktseq,TTC(0));
    ccsds.fillfp(gps.HMS);
    ccsds.fillfp(gps.lat);
    ccsds.fillfp(gps.lon);
    ccsds.fillfp(gps.alt);
    ccsds.finish(ggaApid);
    gps.writeGGA=false;
    Serial.write('g');
  } else if(gps.writeRMC) {
    uint32_t TC=TTC(0);
    ccsds.start(sdStore,rmcApid,pktseq,TC);
    ccsds.fillfp(gps.HMS);
    ccsds.fillfp(gps.lat);
    ccsds.fillfp(gps.lon);
    ccsds.fillfp(gps.spd);
    ccsds.fillfp(gps.hdg);
    ccsds.fill32(gps.DMY);
    ccsds.finish(rmcApid);
    Serial.write('r');
    gps.writeRMC=false;
    hasGuide=true;
  }
  return hasGuide;
}

void loop() {
  if(f.size()>=maxLogSize) {
    closeLog();
    openLog();
    sdStore.fill(syncMark);
    sdStore.mark();
  }
  collectMpuData(0x09);
  collectMagData(0x0A);
  collectBmpData(0x0B);
  collectGPS(0x0C,0x0D,0x0E,0x0F);
  sdStore.drain();
}

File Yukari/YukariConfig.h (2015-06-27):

#ifndef YukariConfig_h
#define YukariConfig_h
const unsigned char channelThrottle=6;    //PWM6, attached to RX1
const unsigned char channelSteer=4; //PWM4, attached to TX1
const int right=-1;
const int left=-right;
const int forward=1;
const int reverse=-forward;
const unsigned int channelTCPPS=0;
const unsigned int channelTCGyro=3;
const unsigned int channelTCBtn=2;
const unsigned int adEncoder0=6; //Use AD pin 6
const unsigned int adEncoder1=7;
#endif

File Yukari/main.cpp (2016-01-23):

#include <string.h>
#include "Time.h"
#include "LPCduino.h"
#include "StateTwoWire.h"
#include "hmc5883.h"
#include "float.h"
#include "Serial.h"
#include "HardSPI.h"
#include "l3g4200d.h"
#include "sdhc.h"
#include "Partition.h"
#include "cluster.h"
#include "direntry.h"
#include "file.h"
#include "FileCircular.h"
#include "dump.h"
#include "nmea.h"
#include "readconfig.h"
#include "config.h"
#include "navigate.h"
#include "ccsds.h"
#include "guide.h"
#include "control.h"
#include "pwm.h"
//#include "kalman.h"
#include "YukariConfig.h"

const char syncMark[]="KwanSync";
static const char version_string[]="Project Yukari v4.0 " __DATE__ " " __TIME__;
const int dumpPktSize=120;

CCSDS packet;
HMC5883 hmc5883;
SDHC sd;
L3G4200D gyro;
SDHC_info sdinfo;
Partition p(sd);
Cluster fs(p);
File f(fs);
FileCircular sdStore(f);
char serialBuf[1024];
Circular serialStore(1024,serialBuf);
NMEA gps;
ReadConfig readconfig(fs,packet);
Navigate nav(config);
Guide guide(nav,config);
Control control(nav,guide,config);

const unsigned char channelMask=(1<<channelSteer)|(1<<channelThrottle);

uint16_t log_i=0;

const uint32_t readPeriodMs=100;
unsigned int ppsTC,btnTC;
int16_t bx,by,bz,gx,gy,gz;

void flushPackets() {
//  static int flickerState=0;
  if(sdStore.drain()) {
//    flickerState=1-flickerState;
//    set_pin(8,0,1);
//    gpio_write(8,flickerState);
  }
  if(sdStore.errnum!=0) { 
    Serial.print("Problem writing file: sdStore.errnum=");
    Serial.println(sdStore.errnum);
    blinklock(sdStore.errnum);
  }
}

void collectMagData() {
  static unsigned int magPhase=0;
  const unsigned int magMaxPhase=10;
  static unsigned int bTC;
  if(magPhase>=magMaxPhase) {
    bTC=TTC(0);
    hmc5883.read(bx,by,bz);
    //Sensor registers are in X, Z, Y order, not XYZ. Old code didn't know this,
    //wrote sensor registers in order, therefore wrote xzy order unintentionally.
    //We will keep this order to maintain compatibility with old data, including
    //flight 36.290
    #include "write_packet_mag.INC"
    magPhase=0;
  }
  magPhase++;
}

//return true if sensor has updated the heading
bool collectGyroData() {
  unsigned int gTCR=TCR(0,channelTCGyro);
  static unsigned int gTC;
  if(gTCR!=gTC) {
    gTC=gTCR;
    uint8_t t,status;
    gyro.read(gx,gy,gz,t,status);
    unsigned int gTC1=TTC(0);
    Vector<3> meas;
    meas[0]=gx;
    meas[1]=gy;
    meas[2]=gz;
    nav.handleGyro(gTC,meas);
    #include "write_packet_nav2.INC"
    flushPackets();
    return nav.hasButton;
  }
  return false;
}

void openLog(uint16_t inc=1) {
  Serial.println(inc,DEC);
  Serial.println(log_i,DEC);
  if(inc==0) blinklock(108);
  static char fn[13];
  if(fn[0]!='r') strcpy(fn,"yukari00.sds");
  Serial.println(fn);
  while(log_i<99 && f.find(fn)) {
    log_i+=inc;
//    fn[4]='0'+log_i/1000;
//    fn[5]='0'+(log_i%1000)/100;
    fn[6]='0'+(log_i%100)/10;
    fn[7]='0'+(log_i%10);
    Serial.println(fn);
  }
  bool worked=f.openw(fn);
  Serial.print("f.openw(\"");Serial.print(fn);Serial.print("\"): ");Serial.print(worked?"Worked":"didn't work");Serial.print(". Status code ");Serial.println(f.errnum);
  if(!worked) blinklock(f.errnum);
}

void closeLog() {
  f.close(); //Sync the directory entry - after this, we may reuse this file
               //object on a new file.
}

void initSD() {
  bool worked;
  sd.p0=7;
  Serial.print("sd.p0=");
  Serial.println(sd.p0);
  worked=sd.begin();

  Serial.print("sd");    Serial.print(".begin ");Serial.print(worked?"Worked":"didn't work");Serial.print(". Status code ");Serial.println(sd.errnum);
  if(!worked) blinklock(sd.errnum);
  sd.get_info(sdinfo);
  sdinfo.print(Serial);

  worked=p.begin(1);
  Serial.print("p");     Serial.print(".begin ");Serial.print(worked?"Worked":"didn't work");Serial.print(". Status code ");Serial.println(p.errnum);
  p.print(Serial);
  if(!worked) blinklock(p.errnum);

  worked=fs.begin();  
  Serial.print("fs");    Serial.print(".begin ");Serial.print(worked?"Worked":"didn't work");Serial.print(". Status code ");Serial.println(fs.errnum);
//  sector.begin();
  fs.print(Serial);//,sector);

  if(!worked) blinklock(fs.errnum);

  openLog();
  sdStore.fill(syncMark);
  sdStore.mark();

}

void initHMC5883() {
  hmc5883.begin();
  Serial.println("HMC5883 started");
  char HMCid[4];
  hmc5883.whoami(HMCid);
  Serial.print("HMC5883L identifier (should be 'H43'): ");
  Serial.println(HMCid);
  packet.start(sdStore,0x0E);
  hmc5883.fillConfig(packet);
  packet.finish(0x0E);
  sdStore.drain();
}

void initGyro() {
  gyro.begin(config.gyroSens,config.gyroODR,config.gyroBW); //Use sensitivity specified in config file. Actual
                               //sensitivity is 250*2^config.gyroSens deg/s full scale
  Serial.println("L3G4200D started");
  uint8_t gyroId=gyro.whoami();
  Serial.print("L3G4200D identifier (should be 'D3'): ");
  Serial.println(gyroId,HEX,2);
  nav.setSens(config.gyroSens);
  packet.start(sdStore,0x20);
  gyro.fillConfig(packet);
  packet.finish(0x20);
  sdStore.drain();
  //Priming read, not written anywhere but clears INT2
  uint8_t t,status;
  gyro.read(gx,gy,gz,t,status);
  //set up CAP0.3 on pin P0.29 (Loginator AD2, 11DoF IG) to capture (read) gyro INT2
  setup_cap(29,true,false,false);
}

void initButtons() {
  //PPS is wired to AD5, P0.22, CAP0.0
  setup_cap(22,true,false,false);
  setup_cap(22,0x01);
  ppsTC=0;
  //Use the STOP button to start (I know). STOP is wired to P0.16, CAP0.2
  setup_cap(16,true,false,false);
  btnTC=0;
}

void writeVersion() {
  #include "write_packet_version.INC"
  sdStore.drain();
}

void setupWaypointPacket(int context) {
  #include "write_packet_wpt.INC"
  flushPackets();
}
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

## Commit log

2012-10-29 Copy of Loginator hardware design to test compression, various compression methods implemented, max.zpaq current favorite
2012-11-01 Reorganized compression and linker script
    [Rocketometer.brd, Rocketometer.sch]
2012-11-10 Gyro changed to read temperature sensor as well
2012-11-14 Added full error handling to all file-handling classes
    [main.cpp]
2012-11-25 Readout now at 600Hz
2013-02-01 Changes to ad799x to make it quicker to read the device into a packet
2013-02-21 One shining moment for Rocketometer, before unification of packet and print
2013-02-24 As (attempted to be) flown 23 Feb 2013
2013-03-05 Starting on USB driver
2013-03-14 Started on Loginator USB driver
2013-11-09 First cut at GPS parser - written with pointers to member functions
2014-01-10 Shuffled several documents
    [Apid.ods]
2014-03-14 Pinewood now reads the analog sensor
2014-03-14 Added as-built board designs. In Eagle 5, so binary, not XML
    [11Dof.brd, 11Dof.sch, Apid.ods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]
2014-04-27 One Shining Moment - PWMExample1 can steer Yukari
    [Loginator.brd, Loginator.sch]
2014-06-18 Starting final push on YukariII
    [11Dof.brd, 11Dof.sch, Apid.ods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]
2014-06-20 Started on compass filter
2014-06-20 Keep working on compass filter
2014-06-21 Packing up for move to Natsumi
    [CONFIG.TXT, Waypoints.ods]
2014-06-24 Back home from unsuccessful AVC 2014
    [CONFIG.TXT, Waypoints.ods]
2014-11-05 Added Southwest
    [11Dof.brd, 11Dof.sch, CONFIG.TXT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]
2014-11-05 Refactored repository, preparatory to splitting into code and data repositories
    [11Dof.brd, 11Dof.sch, Apid.ods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]
2015-06-27 Remove and rename in preparation for BFG
    [11Dof.brd, 11Dof.sch, Apid.ods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]
2015-12-03 Added Yukari4, changed it over to use templates
    [11Dof.brd, 11Dof.sch, GP-2106_Eval-v11.brd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]
2015-12-16 Renamed Yukari4 to Yukari, put Yukari3 into Yukari4/v3, deleted code from v3 that had already been transferred, deleted YukariII. If we have a version control system, we should use it rather than ver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
    [11Dof.brd, 11Dof.sch, CONFIG.TXT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]
2015-12-19 Changed extractPacket to extractPacket.exe . Added SimSd.dot and attached it to source bundle.
2015-12-21 Starting I2C state simulator
2015-12-23 More cleanup
    [11Dof.brd, 11Dof.sch, Apid.ods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]
2016-01-02 Started SPI refactoring
2016-01-07 Added database for Rocketometer which is compatible with new extractPacket.exe
    [RktoDatabase.ods]
2016-01-08 Working on getting Rocketometer back to work
    [RktoDatabase.ods, TelemetryDatabase.ods]
2016-01-09 Changed code back to using virtual methods instead of CRTP
    [TelemetryDatabase.ods]
2016-01-12 Starting to add hardware description stuff
    [11DoF.ods, GPS.ods, LoginatorOnboard.ods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]
2016-01-13 Finished hardwareDesc and SimId
    [LoginatorHardware.ods]
2016-01-14 Continuing to work on hardwareDesc, more internal to the embedded code now
    [11DoF.ods, GPS.ods, LoginatorHardware.ods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]
2016-01-16 Added Eigen, reimplemented Kalman filter with it
2016-01-16 First scalar constant Kalman filter is working
    [11Dof.brd, 11Dof.sch, GP-2106_Eval-v11.brd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]
2016-01-18 Implemented Kalman Velocity
2016-01-22 Starting on dynamic peripheral setup
    [RocketometerHardware.ods, RocketometerOnboard.ods]
2016-02-10 More cortex-M4 startup stuff
    [11DoF.ods, GPS.ods, Loginator2368Hardware.ods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]
2016-02-12 Have code working, but only with ISP assistance
    [LoginatorOnboard.ods]
2016-02-24 More thumb emulator stuff
    [LPC4078 Undocumented Registers.ods]
2016-03-01 Added knowledge on boot[43c] which is used as the second stack pointer Reconfigured datapath memory from one monolithic block to a list of configuralble memory-like devices Added several devices
2016-03-14 Made UART write work, started UART read, need to add timestamp to strings to read
2016-06-24 Removed extra copies of the Fritzing diagram
    [Yukari3.fzz]

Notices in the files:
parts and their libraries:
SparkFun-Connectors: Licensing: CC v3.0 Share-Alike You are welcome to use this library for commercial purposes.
